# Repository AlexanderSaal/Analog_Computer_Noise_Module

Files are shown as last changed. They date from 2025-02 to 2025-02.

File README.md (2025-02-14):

# Analog_Computer_Noise_Module
A frequency selectable Noise Module in a rack format for analog computing.

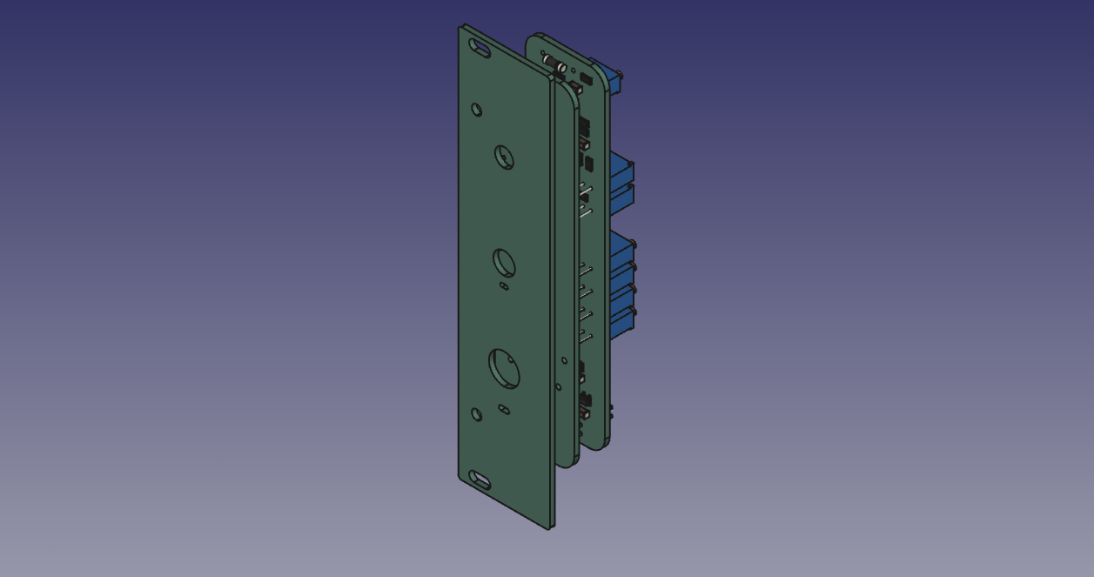
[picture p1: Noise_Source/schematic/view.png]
View of the noise module


## Module Schematic

The noise is taken from a Zener diode, then slightly amplified and DC shifted to be feed into a low pass filter. The cutoff frequency can be selected with a rotary switch, which operates an adjustable oscillator. The signal is DC offset corrected after the filter and then amplified.

<ins> Noise: </ins>\
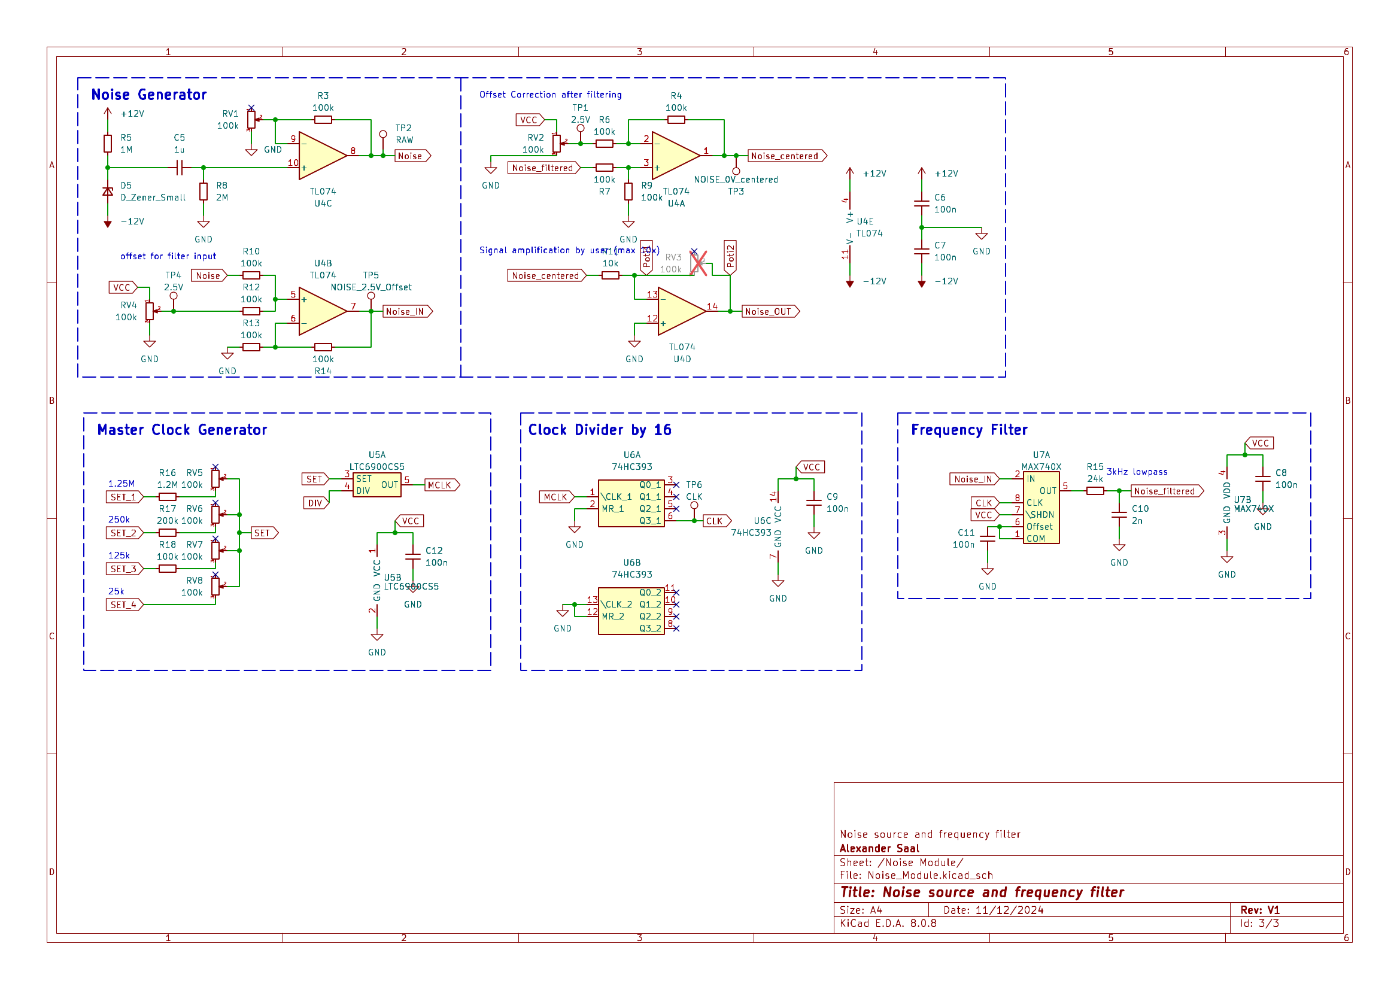
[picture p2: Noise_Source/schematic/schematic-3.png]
Schematic of the Division Module Circuit implementation of the Division Module


This module is largely based on [Bernd Ulmanns design and his archive in the Analogmuseum](https://analogmuseum.org/english/homebrew/noise_filter/) (last visited Dec. 2024). It even has the same frequency steps of: 1, 5, 10, 50, 100, 500 and 1000 $Hz$.

The Noise source is based on a Zener diode, following an article of [Steve Hageman on EDN, with the title: White noise source flat from 1Hz to 100kHz](https://www.edn.com/white-noise-source-flat-from-1hz-to-100khz/) (last visited Dec. 2024).

## Issues

The linear power regulator NCP718xSN500 (U1) overheats within seconds. Although it can handle the current, I did not account for the dissipated power. For a $12\,V$ input, the power dissipation is approximately $0.5\,W$, which immediately triggers a thermal shutdown. This failure cascades through the system, shutting down all components on the $+5V$ rail. 

More problematic is the ripple introduced around the diode used as the noise source. It causes slight variations in the single-digit $mV$ range, which pass through the high-pass filter and amplifier, leading to a significant offset voltage after the first stage. The voltage measured at test point $TP2$ is already outside of specifications.

For now, the recommended solution is to either cool or replace the linear power regulator.

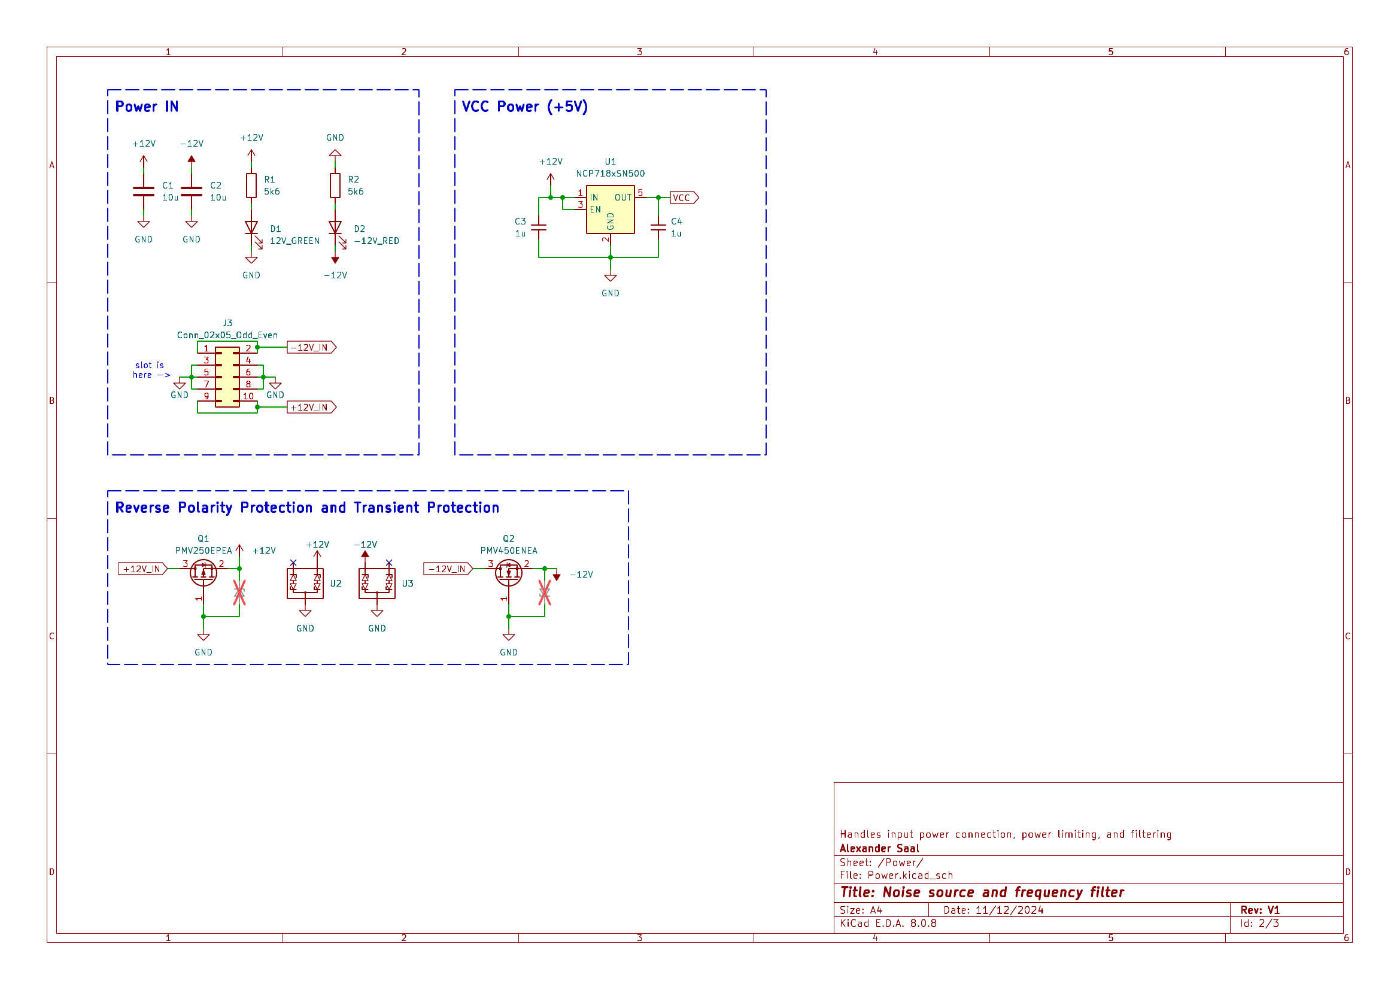
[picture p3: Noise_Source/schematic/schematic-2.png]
Schematic of the Power section


## List of special Components:

- frequency filter :[MAX7407](https://www.digikey.de/en/products/detail/analog-devices-inc-maxim-integrated/MAX7407ESA/1513411)
- oscillator: [LTC6900](https://www.digikey.de/en/products/detail/analog-devices-inc/LTC6900CS5-TRMPBF/1115937)
- Rotary switch, 12 pole, 2 layers: [SWITCH ROTARY 2-12POS](https://www.digikey.de/en/products/detail/grayhill-inc/71BD30-02-1-AJN/98669)

## Bill of materials:

<ins> Main Noise Module: </ins>
| | | | | 
|---|---|---|---|
| References | Value | Footprint | Quantity | 
| C6, C7, C8, C9, C11, C12 | 100n | 1206/3216Metric | 6 | 
| C3, C4, C5 | 1u | 1206/3216Metric | 3 | 
| C1, C2 | 10u | 1206/3216Metric | 2 | 
| C10 | 2n | 1206/3216Metric | 1 | 
| R3, R4, R6, R7, R9, R10, R12, R13, R14, R18 | 100k | 1206/3216Metric | 10 | 
| R1, R2 | 5k6 | 1206/3216Metric | 2 | 
| R5 | 1M | 1206/3216Metric | 1 | 
| R8 | 2M | 1206/3216Metric | 1 | 
| R11 | 10k | 1206/3216Metric | 1 | 
| R15 | 24k | 1206/3216Metric | 1 | 
| R16 | 1.2M | 1206/3216Metric | 1 | 
| R17 | 200k | 1206/3216Metric | 1 | 
| D1 | GREEN Diode | 1206/3216Metric | 1 | 
| D2 | RED Diode | 1206/3216Metric | 1 | 
| D5 | Zener Diode | any | 1 | 
| U2, U3 | VCAN16A2-03S-E3-08  | SOT23-3 | 2 | 
| U1 | NCP718xSN500 | SOT-23-5 | 1 | 
| U4 | TL074 | SOIC-14 | 1 | 
| U5 | LTC6900 | TSOT-23-5 | 1 | 
| U6 | 74HC393 | SOIC-14 | 1 | 
| U7 | MAX740X | SOIC-8 | 1 | 
| RV1, RV2, RV4, RV5, RV6, RV7, RV8 | 100k | Potentiometer_Bourns_3296W_Vertical | 7 | 
| Q1 | PMV250EPEA | SOT-23 | 1 | 
| Q2 | PMV450ENEA | SOT-23 | 1 | 
| J1 | Conn_01x11_Pin | | 1 | 
| J3 | Conn_02x05_Odd_Even | | 1 | 

<ins> Middleplate: </ins>
| | | | | 
|---|---|---|---|
| References | Value | Footprint | Quantity | 
| Poti1, Poti2 | 100k Potentiometer | | 1 |
| | SP12T switch, 2 layers | | 1 |
| | 2mm banana plug socket | | 1 |

## License

This work is published under the [CERN Open Hardware Licence Version 2 - Strongly Reciprocal](LICENSE)

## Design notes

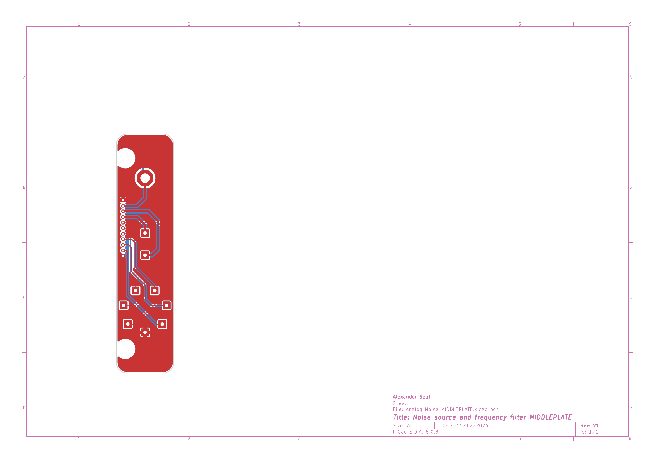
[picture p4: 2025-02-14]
Middleplate/schematic/PCB-1.png

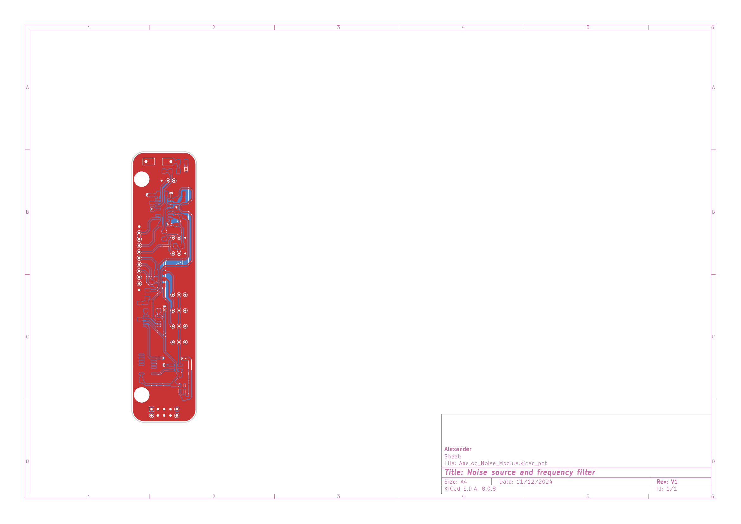
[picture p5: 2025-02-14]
Noise_Source/schematic/PCB-1.png

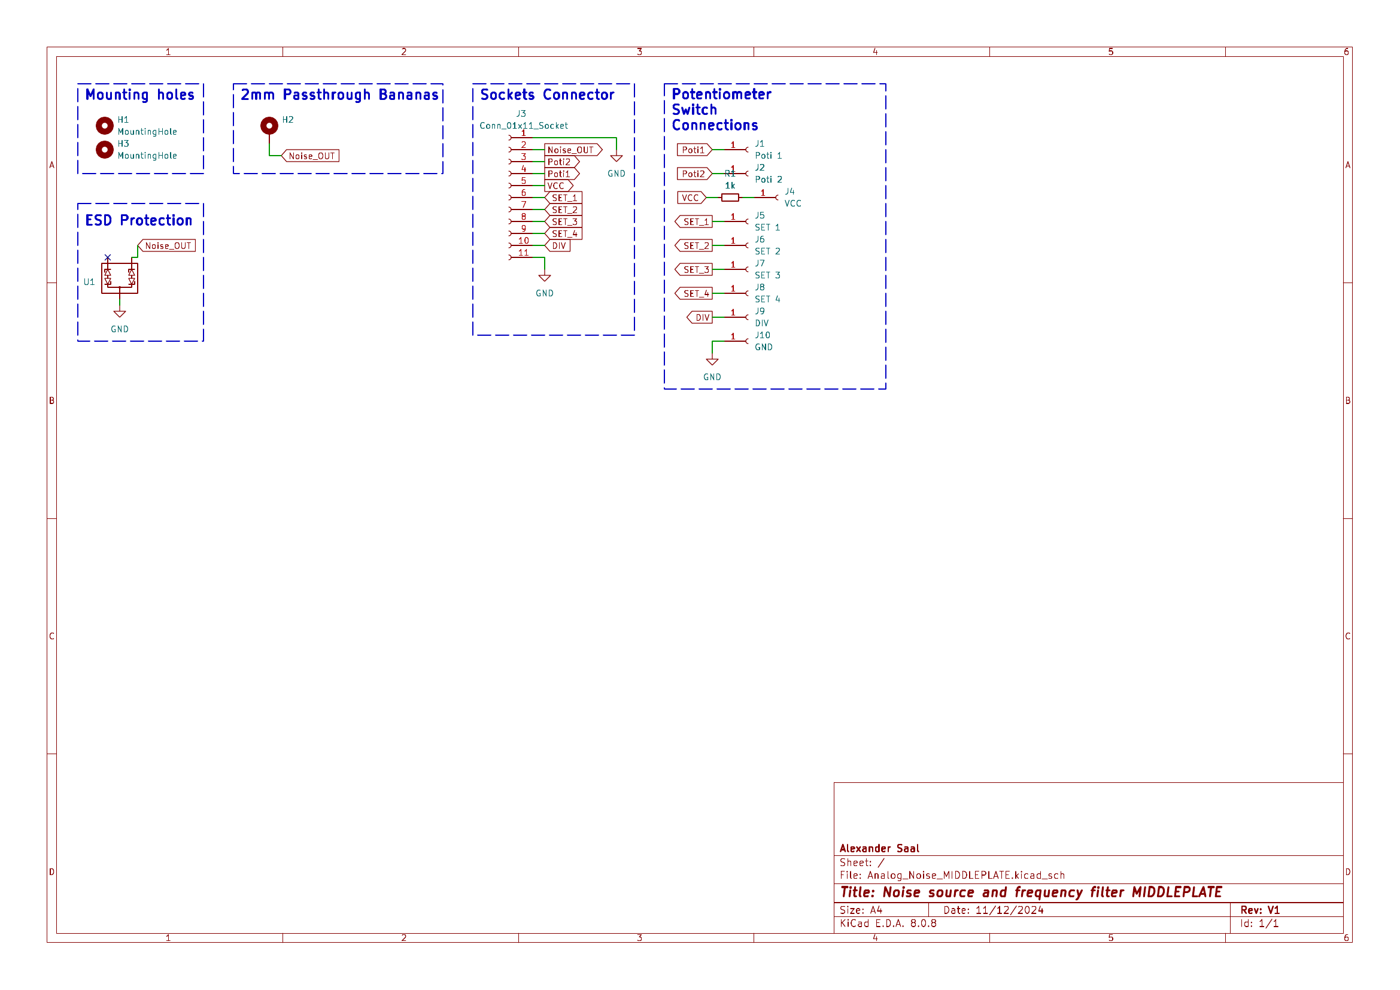
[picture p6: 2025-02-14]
Middleplate/schematic/schematic-1.png

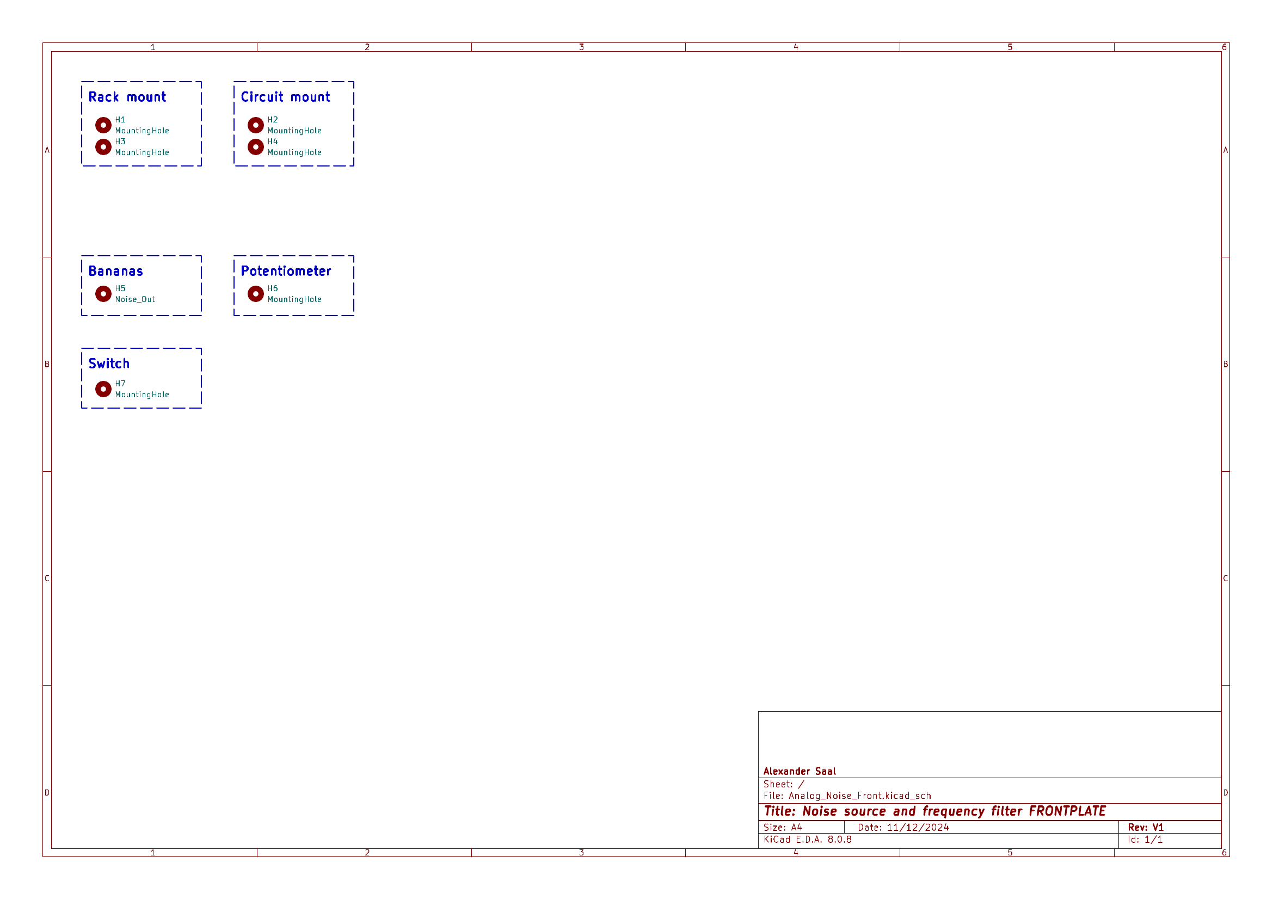
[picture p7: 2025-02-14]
Frontplate/schematic/schematic-1.png

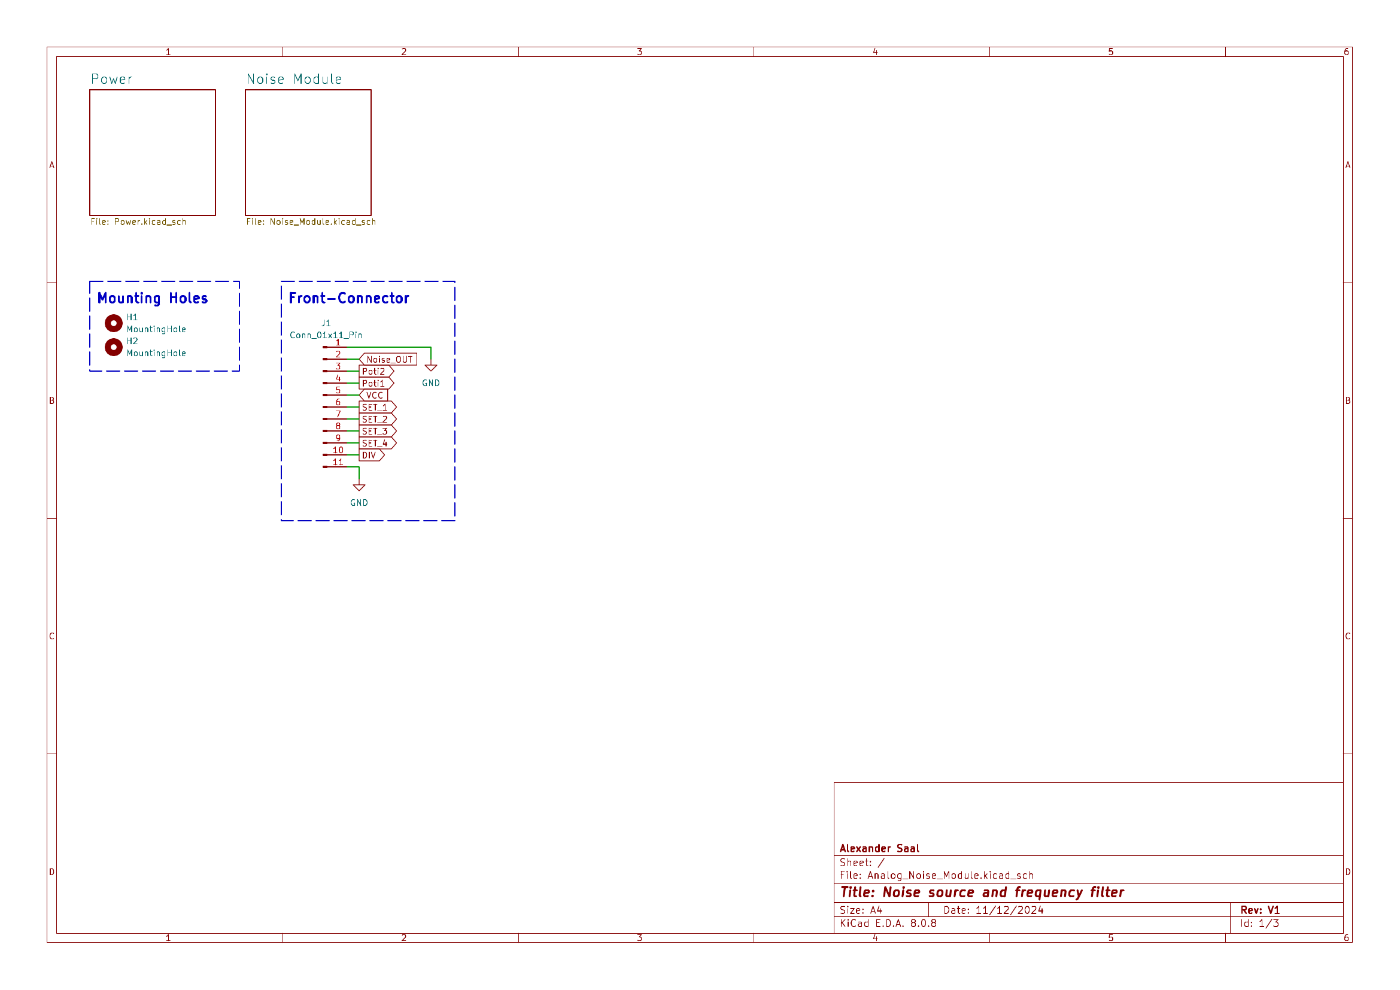
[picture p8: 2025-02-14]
Noise_Source/schematic/schematic-1.png

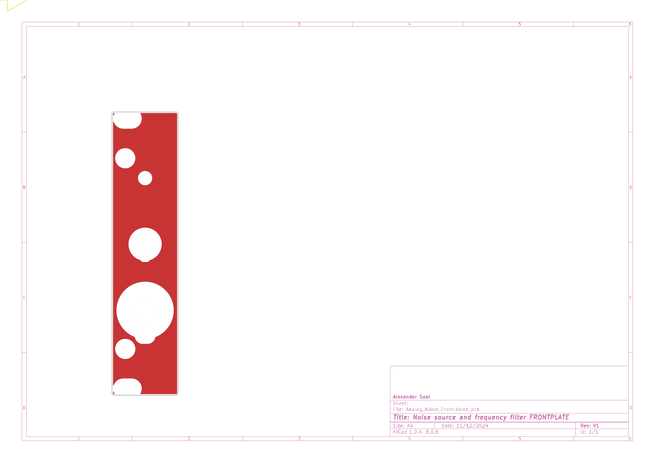
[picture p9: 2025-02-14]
Frontplate/schematic/PCB-1.png

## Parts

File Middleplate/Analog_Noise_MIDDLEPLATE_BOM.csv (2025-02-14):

Reference | Value | Footprint | QUANTITY
J1 | Poti 1 | Connector_Wire:SolderWire-0.75sqmm_1x01_D1.25mm_OD3.5mm | 1
J2 | Poti 2 | Connector_Wire:SolderWire-0.75sqmm_1x01_D1.25mm_OD3.5mm | 1
J3 | Conn_01x11_Socket | Connector_PinSocket_2.54mm:PinSocket_1x11_P2.54mm_Vertical | 1
J4 | VCC | Connector_Wire:SolderWire-0.75sqmm_1x01_D1.25mm_OD3.5mm | 1
J5 | SET 1 | Connector_Wire:SolderWire-0.75sqmm_1x01_D1.25mm_OD3.5mm | 1
J6 | SET 2 | Connector_Wire:SolderWire-0.75sqmm_1x01_D1.25mm_OD3.5mm | 1
J7 | SET 3 | Connector_Wire:SolderWire-0.75sqmm_1x01_D1.25mm_OD3.5mm | 1
J8 | SET 4 | Connector_Wire:SolderWire-0.75sqmm_1x01_D1.25mm_OD3.5mm | 1
J9 | DIV | Connector_Wire:SolderWire-0.75sqmm_1x01_D1.25mm_OD3.5mm | 1
J10 | GND | Connector_Wire:SolderWire-0.75sqmm_1x01_D1.25mm_OD3.5mm | 1
R1 | 1k | Resistor_SMD:R_1206_3216Metric_Pad1.30x1.75mm_HandSolder | 1
U1 | VCAN16A2-03S-E3-08 | analog_computing:VCAN16A2-03S-E3-08 | 1

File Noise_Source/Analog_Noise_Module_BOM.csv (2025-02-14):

Reference | Value | Footprint | QUANTITY
C1,C2 | 10u | Capacitor_SMD:C_1206_3216Metric_Pad1.33x1.80mm_HandSolder | 2
C3-C5 | 1u | Capacitor_SMD:C_1206_3216Metric_Pad1.33x1.80mm_HandSolder | 3
C6-C9,C11,C12 | 100n | Capacitor_SMD:C_1206_3216Metric_Pad1.33x1.80mm_HandSolder | 6
C10 | 2n | Capacitor_SMD:C_1206_3216Metric_Pad1.33x1.80mm_HandSolder | 1
D1 | 12V_GREEN | LED_SMD:LED_1206_3216Metric | 1
D2 | -12V_RED | LED_SMD:LED_1206_3216Metric | 1
D5 | D_Zener_Small | Diode_SMD:D_MELF-RM10_Universal_Handsoldering | 1
J1 | Conn_01x11_Pin | Connector_PinHeader_2.54mm:PinHeader_1x11_P2.54mm_Vertical | 1
J3 | Conn_02x05_Odd_Even | Connector_PinHeader_2.54mm:PinHeader_2x05_P2.54mm_Vertical | 1
Q1 | PMV250EPEA | Package_TO_SOT_SMD:SOT-23_Handsoldering | 1
Q2 | PMV450ENEA | Package_TO_SOT_SMD:SOT-23_Handsoldering | 1
R1,R2 | 5k6 | Resistor_SMD:R_1206_3216Metric_Pad1.30x1.75mm_HandSolder | 2
R3,R4,R6,R7,R9,R10,R12-R14,R18 | 100k | Resistor_SMD:R_1206_3216Metric_Pad1.30x1.75mm_HandSolder | 10
R5 | 1M | Resistor_SMD:R_1206_3216Metric_Pad1.30x1.75mm_HandSolder | 1
R8 | 2M | Resistor_SMD:R_1206_3216Metric_Pad1.30x1.75mm_HandSolder | 1
R11 | 10k | Resistor_SMD:R_1206_3216Metric_Pad1.30x1.75mm_HandSolder | 1
R15 | 24k | Resistor_SMD:R_1206_3216Metric_Pad1.30x1.75mm_HandSolder | 1
R16 | 1.2M | Resistor_SMD:R_1206_3216Metric_Pad1.30x1.75mm_HandSolder | 1
R17 | 200k | Resistor_SMD:R_1206_3216Metric_Pad1.30x1.75mm_HandSolder | 1
RV1,RV2,RV4-RV8 | 100k | Potentiometer_THT:Potentiometer_Bourns_3296W_Vertical | 7
TP1,TP4 | 2.5V | TestPoint:TestPoint_Pad_D2.0mm | 2
TP2 | RAW | TestPoint:TestPoint_Pad_D2.0mm | 1
TP3 | NOISE_0V_centered | TestPoint:TestPoint_Pad_D2.0mm | 1
TP5 | NOISE_2.5V_Offset | TestPoint:TestPoint_Pad_D2.0mm | 1
TP6 | CLK | TestPoint:TestPoint_Pad_D2.0mm | 1
U1 | NCP718xSN500 | Package_TO_SOT_SMD:SOT-23-5 | 1
U2,U3 | VCAN16A2 | analog_computing:VCAN16A2-03S-E3-08 | 2
U4 | TL074 | Package_SO:SOIC-14_3.9x8.7mm_P1.27mm | 1
U5 | LTC6900CS5 | Package_TO_SOT_SMD:TSOT-23-5_HandSoldering | 1
U6 | 74HC393 | Package_SO:SOIC-14_3.9x8.7mm_P1.27mm | 1
U7 | MAX740X | Package_SO:SOIC-8_3.9x4.9mm_P1.27mm | 1

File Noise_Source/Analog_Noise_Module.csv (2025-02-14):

Reference | Value | Datasheet | Footprint | Qty | DNP
C1,C2 | 10u | ~ | Capacitor_SMD:C_1206_3216Metric_Pad1.33x1.80mm_HandSolder | 2
C3,C4,C5 | 1u | ~ | Capacitor_SMD:C_1206_3216Metric_Pad1.33x1.80mm_HandSolder | 3
C6,C7,C8,C9,C11,C12 | 100n | ~ | Capacitor_SMD:C_1206_3216Metric_Pad1.33x1.80mm_HandSolder | 6
C10 | 2n | ~ | Capacitor_SMD:C_1206_3216Metric_Pad1.33x1.80mm_HandSolder | 1
D1 | 12V_GREEN | ~ | LED_SMD:LED_1206_3216Metric | 1
D2 | -12V_RED | ~ | LED_SMD:LED_1206_3216Metric | 1
D5 | D_Zener_Small | ~ | Diode_SMD:D_MELF-RM10_Universal_Handsoldering | 1
J1 | Conn_01x11_Pin | ~ | Connector_PinHeader_2.54mm:PinHeader_1x11_P2.54mm_Vertical | 1
J3 | Conn_02x05_Odd_Even | ~ | Connector_PinHeader_2.54mm:PinHeader_2x05_P2.54mm_Vertical | 1
Q1 | PMV250EPEA | ~ | Package_TO_SOT_SMD:SOT-23_Handsoldering | 1
Q2 | PMV450ENEA | ~ | Package_TO_SOT_SMD:SOT-23_Handsoldering | 1
R1,R2 | 5k6 | ~ | Resistor_SMD:R_1206_3216Metric_Pad1.30x1.75mm_HandSolder | 2
R3,R4,R6,R7,R9,R10,R12,R13,R14,R18,RV1,RV2,RV4,RV5,RV6,RV7,RV8 | 100k | ~ | -- mixed values -- | 17
R5 | 1M | ~ | Resistor_SMD:R_1206_3216Metric_Pad1.30x1.75mm_HandSolder | 1
R8 | 2M | ~ | Resistor_SMD:R_1206_3216Metric_Pad1.30x1.75mm_HandSolder | 1
R11 | 10k | ~ | Resistor_SMD:R_1206_3216Metric_Pad1.30x1.75mm_HandSolder | 1
R15 | 24k | ~ | Resistor_SMD:R_1206_3216Metric_Pad1.30x1.75mm_HandSolder | 1
R16 | 1.2M | ~ | Resistor_SMD:R_1206_3216Metric_Pad1.30x1.75mm_HandSolder | 1
R17 | 200k | ~ | Resistor_SMD:R_1206_3216Metric_Pad1.30x1.75mm_HandSolder | 1
TP1,TP4 | 2.5V | ~ | TestPoint:TestPoint_Pad_D2.0mm | 2
TP2 | RAW | ~ | TestPoint:TestPoint_Pad_D2.0mm | 1
TP3 | NOISE_0V_centered | ~ | TestPoint:TestPoint_Pad_D2.0mm | 1
TP5 | NOISE_2.5V_Offset | ~ | TestPoint:TestPoint_Pad_D2.0mm | 1
TP6 | CLK | ~ | TestPoint:TestPoint_Pad_D2.0mm | 1
U1 | NCP718xSN500 | https://www.onsemi.com/pub/Collateral/NCP718-D.PDF | Package_TO_SOT_SMD:SOT-23-5 | 1
U2,U3,U5 | ~ |  | -- mixed values -- | 3
U4 | TL074 | http://www.ti.com/lit/ds/symlink/tl071.pdf | Package_SO:SOIC-14_3.9x8.7mm_P1.27mm | 1
U6 | 74HC393 |  | Package_SO:SOIC-14_3.9x8.7mm_P1.27mm | 1
U7 | MAX740X |  | Package_SO:SOIC-8_3.9x4.9mm_P1.27mm | 1

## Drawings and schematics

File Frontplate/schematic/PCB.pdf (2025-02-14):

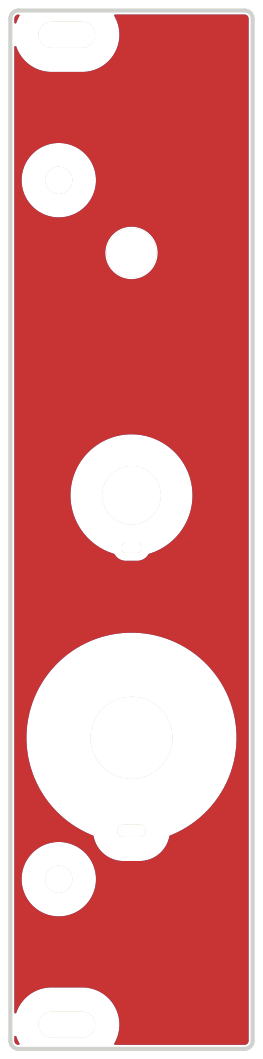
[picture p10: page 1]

File: Analog_Noise_Front.kicad_pcb Sheet: Alexander Saal JLCJLCJLCJLC

Id: 1/1 Title: Noise source and frequency filter FRONTPLATE

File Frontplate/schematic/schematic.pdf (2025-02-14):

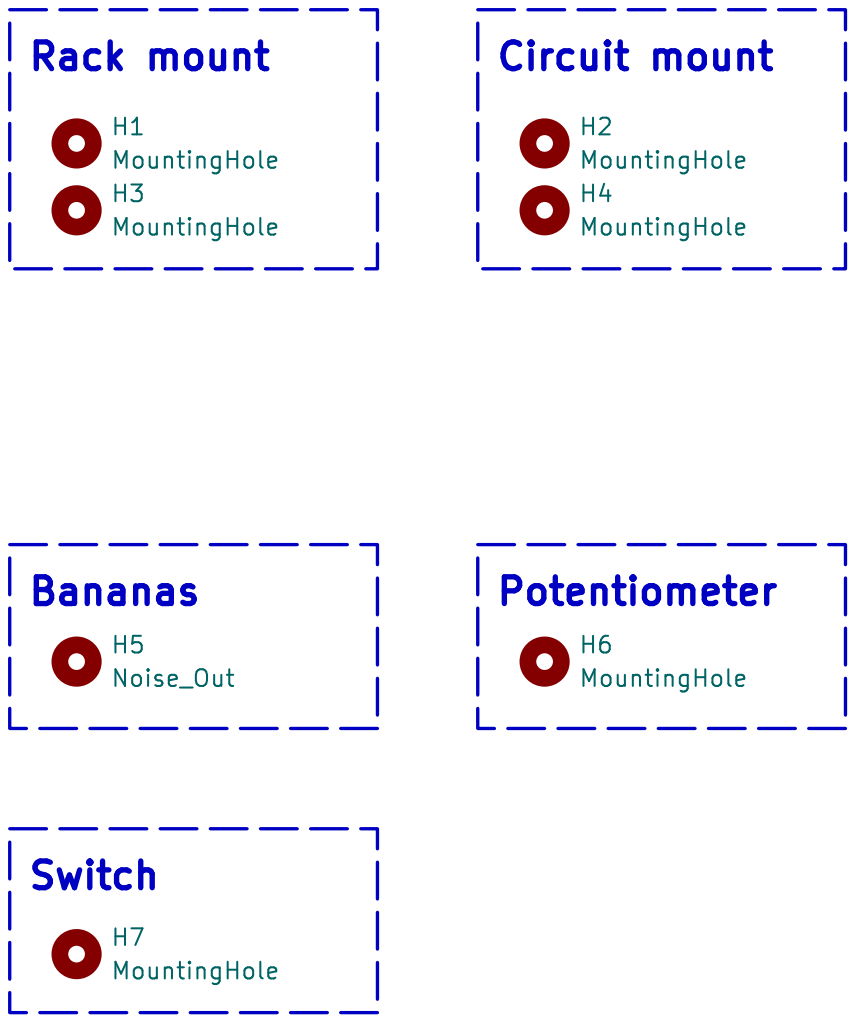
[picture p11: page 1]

File: Analog_Noise_Front.kicad_sch Sheet: / Alexander Saal

Id: 1/1 Title: Noise source and frequency filter FRONTPLATE

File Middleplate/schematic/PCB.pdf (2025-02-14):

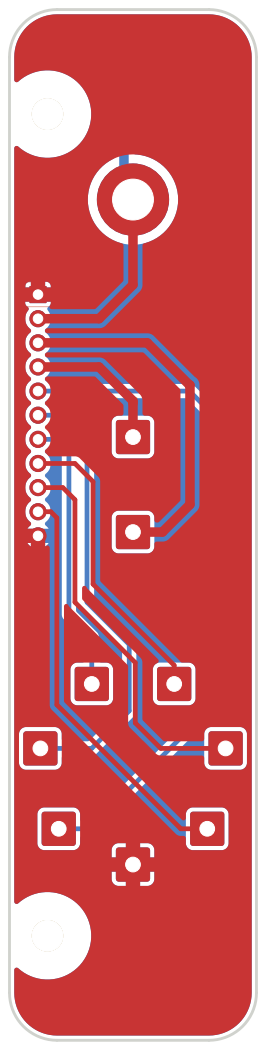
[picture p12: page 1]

Id: 1/1 Title: Noise source and frequency filter MIDDLEPLATE

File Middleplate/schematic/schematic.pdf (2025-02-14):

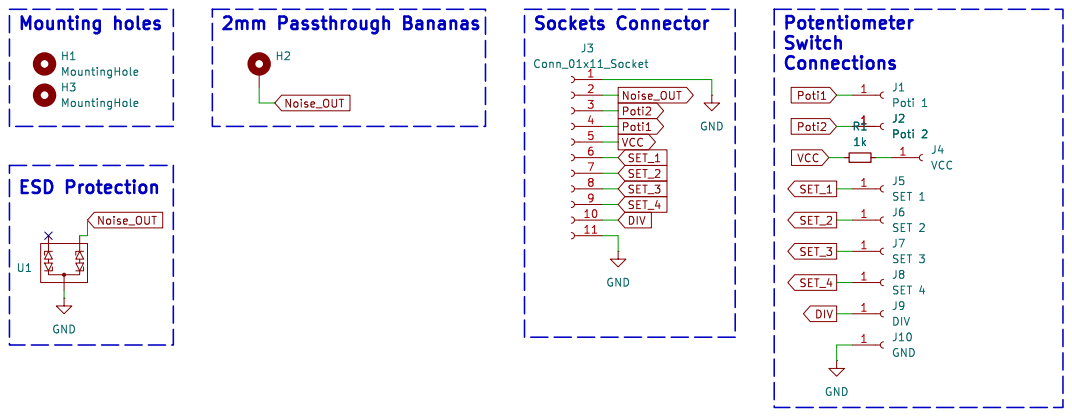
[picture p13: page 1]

File: Analog_Noise_MIDDLEPLATE.kicad_sch Sheet: / Alexander Saal

Id: 1/1 Title: Noise source and frequency filter MIDDLEPLATE

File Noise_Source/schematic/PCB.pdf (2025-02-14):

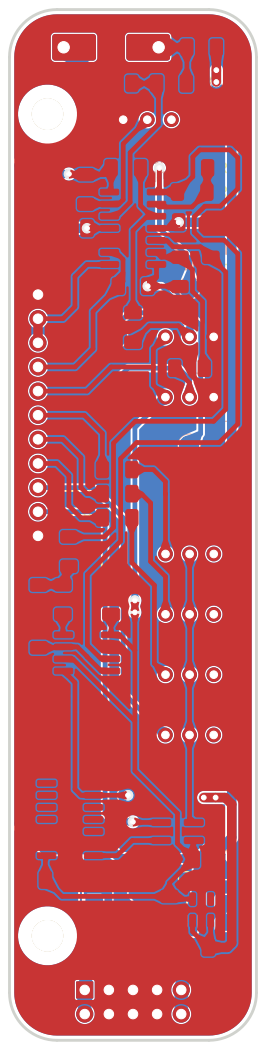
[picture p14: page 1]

amplifier Noise Module V1 Saal 2024

2.5V Noise Offset RAW Noise - 3 Set 1 Set

Id: 1/1 Title: Noise source and frequency filter File: Analog_Noise_Module.kicad_pcb Sheet: Alexander

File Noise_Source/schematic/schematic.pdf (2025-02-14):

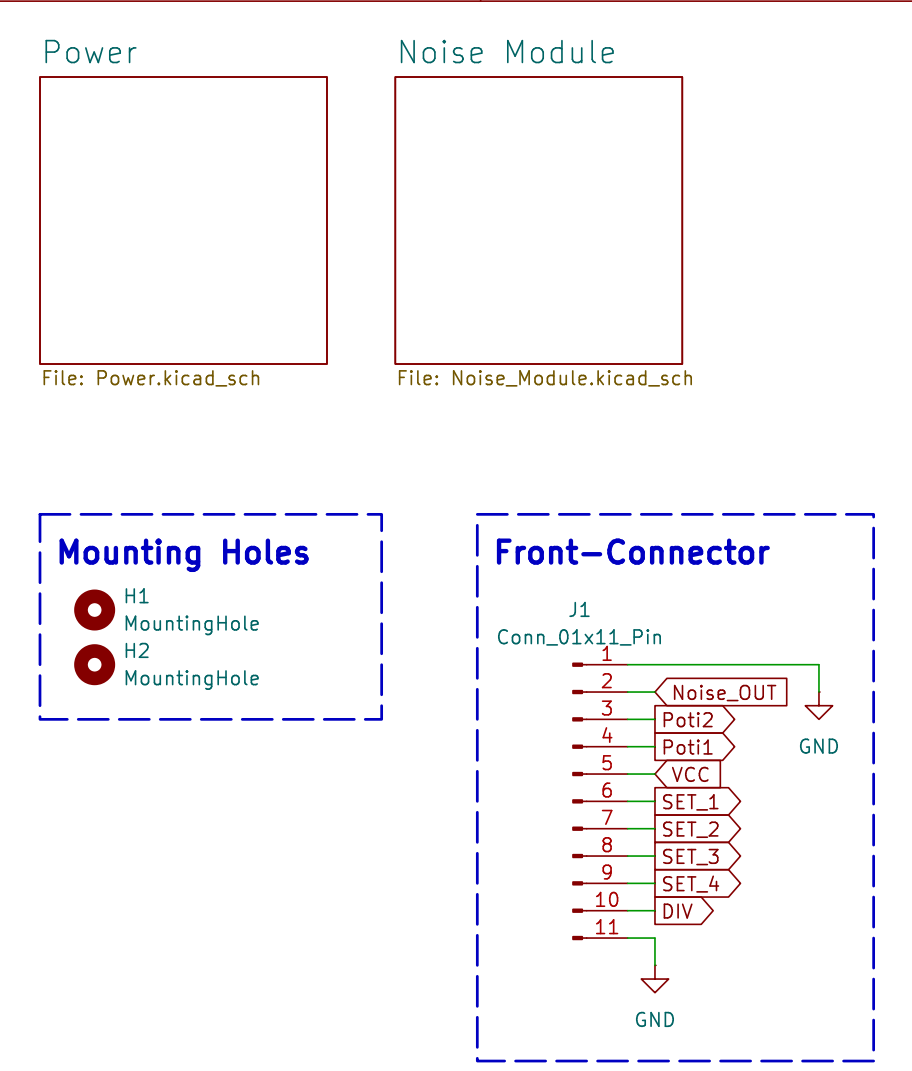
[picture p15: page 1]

Id: 1/3 Title: Noise source and frequency filter File: Analog_Noise_Module.kicad_sch Sheet: / Alexander Saal

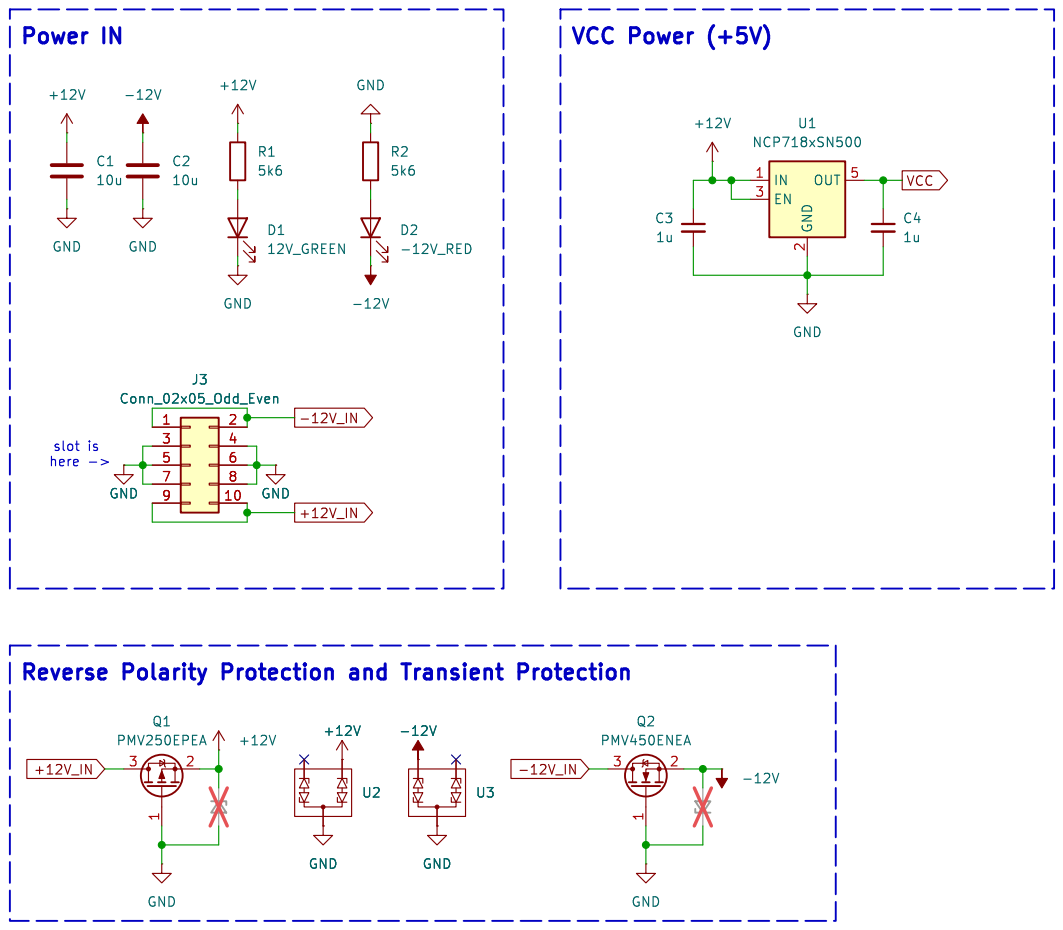
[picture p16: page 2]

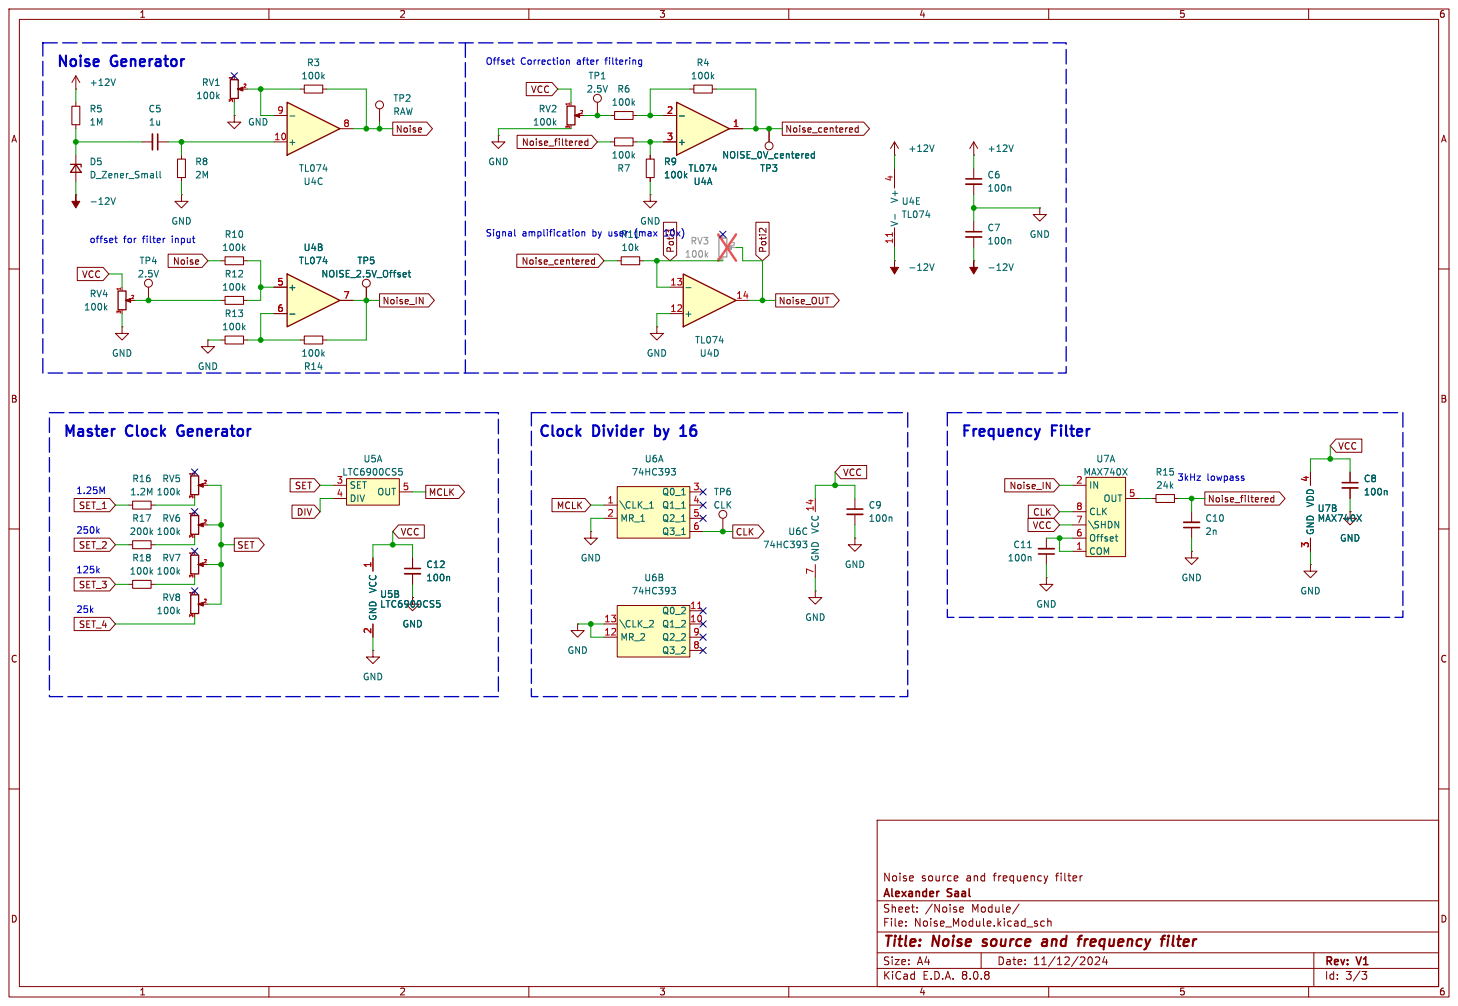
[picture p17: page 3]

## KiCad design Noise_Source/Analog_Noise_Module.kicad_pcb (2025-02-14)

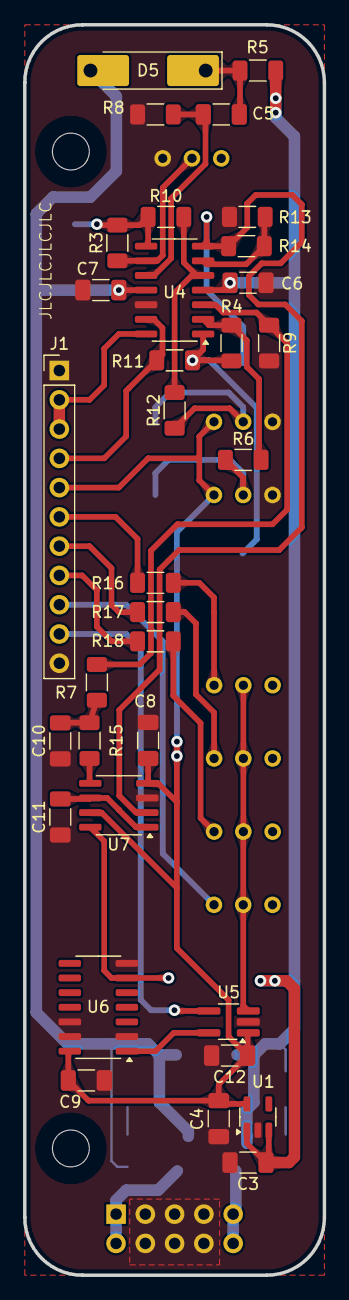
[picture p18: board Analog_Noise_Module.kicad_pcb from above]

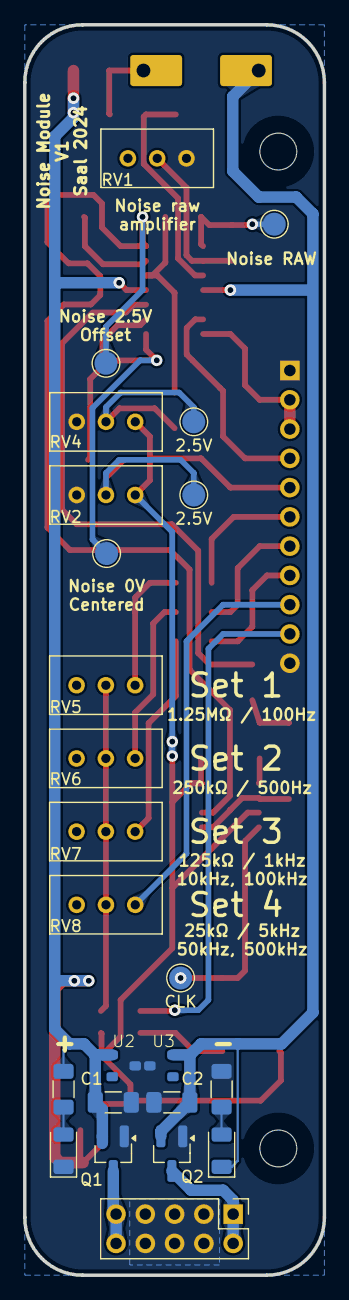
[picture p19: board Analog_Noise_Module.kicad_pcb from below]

Board: 2 copper layers, 26.0 x 108.5 mm, 59 parts (24 on the bottom side), 36 nets.

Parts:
C1, C2: 10u; C_1206_3216Metric_Pad1.33x1.80mm_HandSolder
C3, C4, C5: 1u; C_1206_3216Metric_Pad1.33x1.80mm_HandSolder
C6, C7, C8, C9, C11, C12: 100n; C_1206_3216Metric_Pad1.33x1.80mm_HandSolder
C10: 2n; C_1206_3216Metric_Pad1.33x1.80mm_HandSolder
D1: 12V_GREEN; LED_1206_3216Metric
D2: -12V_RED; LED_1206_3216Metric
D5: D_Zener_Small; D_MELF-RM10_Universal_Handsoldering
H1, H2: MountingHole; MountingHole_3.2mm_M3_DIN965
J1: Conn_01x11_Pin; PinHeader_1x11_P2.54mm_Vertical
J3: Conn_02x05_Odd_Even; PinHeader_2x05_P2.54mm_Vertical
Q1: PMV250EPEA; SOT-23_Handsoldering
Q2: PMV450ENEA; SOT-23_Handsoldering
R1, R2: 5k6; R_1206_3216Metric_Pad1.30x1.75mm_HandSolder
R3, R4, R6, R7, R9, R10, R12, R13, R14, R18: 100k; R_1206_3216Metric_Pad1.30x1.75mm_HandSolder
R5: 1M; R_1206_3216Metric_Pad1.30x1.75mm_HandSolder
R8: 2M; R_1206_3216Metric_Pad1.30x1.75mm_HandSolder
R11: 10k; R_1206_3216Metric_Pad1.30x1.75mm_HandSolder
R15: 24k; R_1206_3216Metric_Pad1.30x1.75mm_HandSolder
R16: 1.2M; R_1206_3216Metric_Pad1.30x1.75mm_HandSolder
R17: 200k; R_1206_3216Metric_Pad1.30x1.75mm_HandSolder
RV1, RV2, RV4, RV5, RV6, RV7, RV8: 100k; Potentiometer_Bourns_3296W_Vertical
TP1, TP4: 2.5V; TestPoint_Pad_D2.0mm
TP2: RAW; TestPoint_Pad_D2.0mm
TP3: NOISE_0V_centered; TestPoint_Pad_D2.0mm
TP5: NOISE_2.5V_Offset; TestPoint_Pad_D2.0mm
TP6: CLK; TestPoint_Pad_D2.0mm
U1: NCP718xSN500; SOT-23-5
U2, U3: VCAN16A2-03S-E3-08
U4: TL074; SOIC-14_3.9x8.7mm_P1.27mm
U5: TSOT-23-5_HandSoldering
U6: 74HC393; SOIC-14_3.9x8.7mm_P1.27mm
U7: MAX740X; SOIC-8_3.9x4.9mm_P1.27mm

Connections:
+12V: C1.1, C3.1, C6.1, Q1.2 (S), R1.1, R5.1, U1.1 (IN), U1.3 (EN), U2.1 (IN1), U4.4 (V+)
+12V_IN: J3.9, J3.10, Q1.3 (D)
-12V: C2.1, C7.2, D2.1 (K), D5.2 (A), Q2.2 (S), U3.2 (IN2), U4.11 (V-)
-12V_IN: J3.1, J3.2, Q2.3 (D)
CLK: TP6.1, U6.6 (Q3_1), U7.8 (CLK)
DIV: J1.10, U5.4 (DIV)
GND: C1.2, C2.2, C3.2, C4.2, C6.2, C7.1, C8.2, C9.2, C10.1, C11.1, C12.2, D1.1 (K), J1.1, J1.11, J3.3, J3.4, J3.5, J3.6, J3.7, J3.8, Q1.1 (G), Q2.1 (G), R2.1, R8.2, R9.2, R13.1, RV1.3, RV2.3, RV4.3, U1.2 (GND), U2.3 (OUT), U3.3 (OUT), U4.12 (+), U5.2 (GND), U6.2 (MR_1), U6.7 (GND), U6.12 (MR_2), U6.13 (\CLK_2), U7.3 (GND)
MCLK: U5.5 (OUT), U6.1 (\CLK_1)
unnamed: D1.2 (A), R1.2
unnamed: D2.2 (A), R2.2
unnamed: C5.2, D5.1 (K), R5.2
unnamed: R6.1, RV2.2, TP1.1
unnamed: R12.1, RV4.2, TP4.1
unnamed: R16.2, RV5.3
unnamed: R17.2, RV6.3
unnamed: R18.2, RV7.3
unnamed: R7.2, R9.1, U4.3 (+)
unnamed: R4.1, R6.2, U4.2 (-)
unnamed: R10.2, R12.2, U4.5 (+)
unnamed: R13.2, R14.1, U4.6 (-)
unnamed: C5.1, R8.1, U4.10 (+)
unnamed: R3.1, RV1.2, U4.9 (-)
unnamed: C11.2, U7.1 (COM), U7.6 (Offset)
unnamed: R15.1, U7.5 (OUT)
Noise: R3.2, R10.1, TP2.1, U4.8
Noise_IN: R14.2, TP5.1, U4.7, U7.2 (IN)
Noise_OUT: J1.2, J1.3, U4.14
Noise_centered: R4.2, R11.1, TP3.1, U4.1
Noise_filtered: C10.2, R7.1, R15.2
Poti1: J1.4, R11.2, U4.13 (-)
SET: RV5.2, RV6.2, RV7.2, RV8.2, U5.3 (SET)
SET_1: J1.6, R16.1
SET_2: J1.7, R17.1
SET_3: J1.8, R18.1
SET_4: J1.9, RV8.3
VCC: C4.1, C8.1, C9.1, C12.1, J1.5, RV2.1, RV4.1, U1.5 (OUT), U5.1 (VCC), U6.14 (VCC), U7.4 (VDD), U7.7 (\SHDN)

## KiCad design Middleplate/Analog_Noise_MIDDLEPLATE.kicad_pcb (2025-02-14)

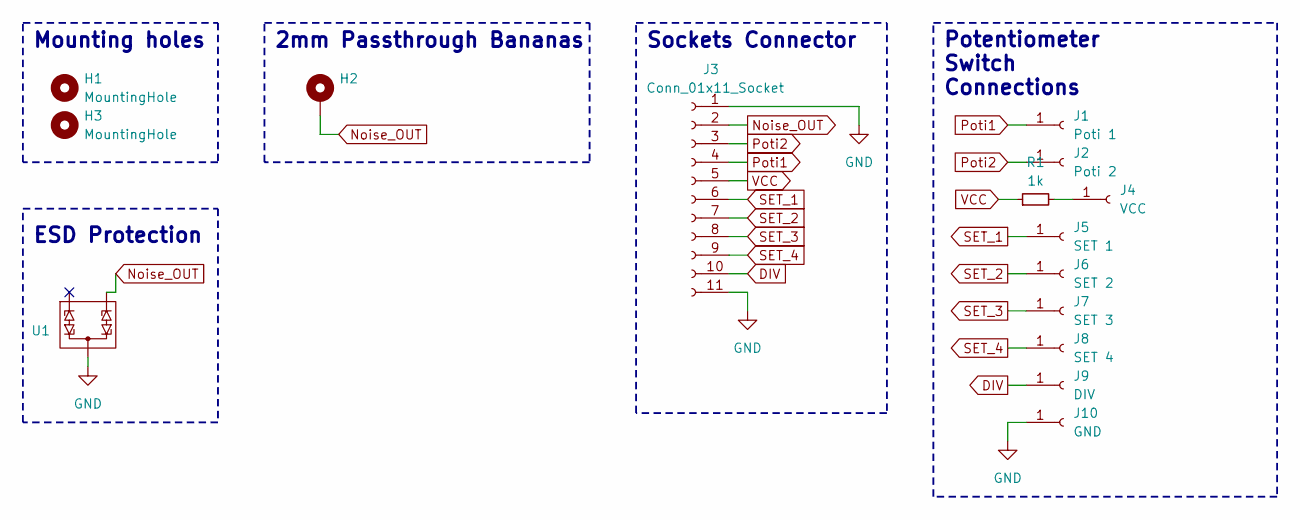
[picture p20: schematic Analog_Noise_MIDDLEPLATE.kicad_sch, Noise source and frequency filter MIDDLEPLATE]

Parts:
H1, H3: MountingHole; MountingHole_3.2mm_M3_DIN965
H2: MountingHole_Pad; MountingHole_4.3mm_M4_DIN965_Pad
J1: Poti 1; SolderWire-0.75sqmm_1x01_D1.25mm_OD3.5mm
J2: Poti 2; SolderWire-0.75sqmm_1x01_D1.25mm_OD3.5mm
J3: Conn_01x11_Socket; PinSocket_1x11_P2.54mm_Vertical
J4: VCC; SolderWire-0.75sqmm_1x01_D1.25mm_OD3.5mm
J5: SET 1; SolderWire-0.75sqmm_1x01_D1.25mm_OD3.5mm
J6: SET 2; SolderWire-0.75sqmm_1x01_D1.25mm_OD3.5mm
J7: SET 3; SolderWire-0.75sqmm_1x01_D1.25mm_OD3.5mm
J8: SET 4; SolderWire-0.75sqmm_1x01_D1.25mm_OD3.5mm
J9: DIV; SolderWire-0.75sqmm_1x01_D1.25mm_OD3.5mm
J10: GND; SolderWire-0.75sqmm_1x01_D1.25mm_OD3.5mm
R1: 1k; R_1206_3216Metric_Pad1.30x1.75mm_HandSolder
U1: VCAN16A2-03S-E3-08

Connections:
DIV: J3.10, J9.1
GND: J3.1, J3.11, J10.1, U1.3 (OUT)
unnamed: J4.1, R1.2
Noise_OUT: H2.1, J3.2, U1.2 (IN2)
Poti1: J1.1, J3.4
Poti2: J2.1, J3.3
SET_1: J3.6, J5.1
SET_2: J3.7, J6.1
SET_3: J3.8, J7.1
SET_4: J3.9, J8.1
VCC: J3.5, R1.1

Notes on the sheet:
Sockets Connector
2mm Passthrough Bananas
Potentiometer Switch Connections
ESD Protection
Mounting holes

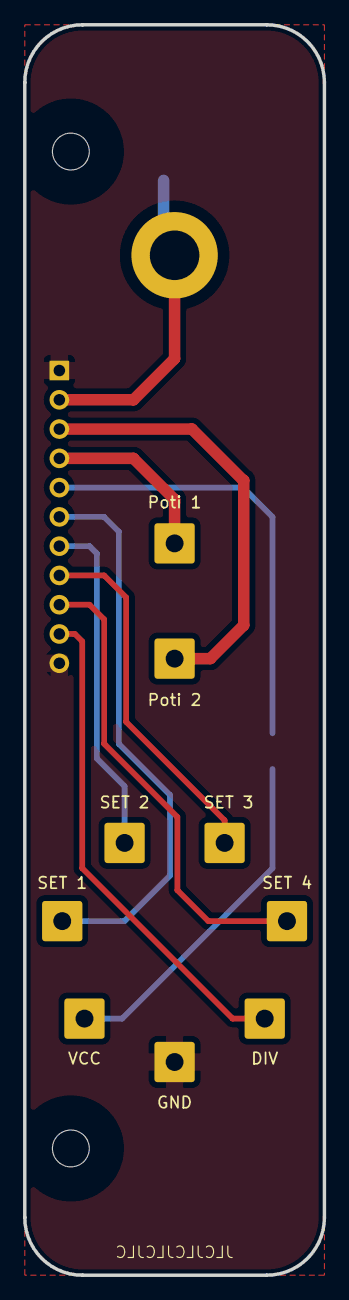
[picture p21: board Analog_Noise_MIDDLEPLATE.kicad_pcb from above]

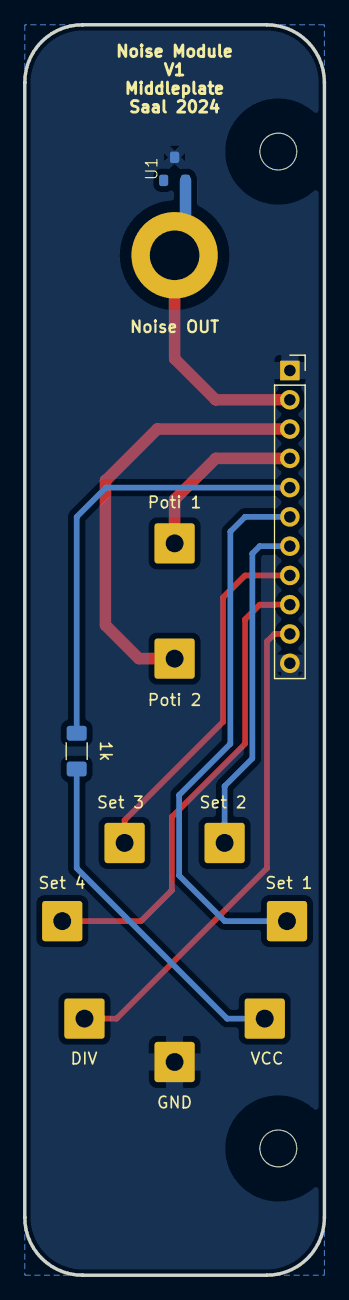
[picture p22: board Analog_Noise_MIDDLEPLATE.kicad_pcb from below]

Board: 2 copper layers, 26.0 x 108.5 mm, 15 parts (3 on the bottom side), 11 nets.
